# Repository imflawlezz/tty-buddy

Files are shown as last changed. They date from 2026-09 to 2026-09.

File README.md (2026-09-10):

# tty-buddy

A small status / console buddy for a Linux box: an **ESP32-C3** driving an
**ST7789 320×240** panel, plus a **Rust host daemon**.

**What it is for.**

Glance at host health without opening a terminal, or use the panel as a tiny
local console. Typical home-lab / desk use: CPU, memory, disk, network,
systemd units, and alerts on one side; a login shell on the other.

**What it does.**

- **Status mode** — live metrics on the LCD (hostname, clock, CPU / MEM /
  DISK, secondary fields, interfaces, services, optional alert strip).
- **Terminal mode** — 53×30 VT mirror of a PTY for a configured
  `shell_user`. A USB keyboard on the **host** (paths/names in
  `keyboard_devices`; empty = idle) is grabbed into that console in terminal
  mode.

The device has one push button for basic device controls. Short press opens
the OSD, or moves to the next row while it is open. Long press changes the
selected setting, or toggles mode when the OSD is closed.

The daemon talks to the board over USB-Serial/JTAG (`303a:1001`).

**Supported platforms**

- **Device** — ESP32-C3 SuperMini (USB-Serial/JTAG) with ST7789 **320×240**.
  Other C3 boards should work as long as the pinout matches.
- **Daemon** — Linux **amd64** and **arm64** (systemd).

Version: `1.1.0`.
License: [MIT](LICENSE).
Changes: [CHANGELOG.md](CHANGELOG.md).

| Path | Contents |
|---|---|
| [`firmware/`](firmware/) | Device firmware (PlatformIO) |
| [`daemon/`](daemon/) | Host daemon + packaging |
| [`hardware/`](hardware/) | Schematic, wiring, enclosure |
| [`docs/`](docs/) | Flashing, daemon lifecycle, config, architecture |

---

## Getting started

**What you need**

- Wired ESP32-C3 + ST7789 ([`hardware/wiring.md`](hardware/wiring.md))
- Merged factory firmware: `tty-buddy-firmware-<version>.bin`
- Daemon package (`.deb` or tarball) from a [GitHub Release](https://github.com/imflawlezz/tty-buddy/releases) or `make release`
- Linux host for the daemon (amd64 or arm64)

### Flash the board

#### In the browser

Chrome or Edge **89+** (Web Serial). Firefox and Safari are not supported.
Use HTTPS pages (the hosted tools already are).

| Tool | URL |
|---|-----|
| Espressif esptool-js | [espressif.github.io/esptool-js](https://espressif.github.io/esptool-js/) |
| Adafruit WebSerial ESPTool | [adafruit.github.io/Adafruit_WebSerial_ESPTool](https://adafruit.github.io/Adafruit_WebSerial_ESPTool/) |

Connect the board, choose the serial port, select the factory `.bin`, flash
at offset **0x0** (full image). Steps and troubleshooting:
[`docs/guides/flashing.md`](docs/guides/flashing.md).

If a daemon is already running, free the serial port before flashing:

```bash
sudo systemctl stop 'tty-buddy@*' 'tty-buddy-board@*'
```

#### On the machine (board on USB):

```bash
# from a release artifact or make firmware → dist/
cd firmware
./scripts/flash.sh /path/to/tty-buddy-firmware-<version>.bin
```

Optional port override:

```bash
./scripts/flash.sh --port /dev/ttyACM0 /path/to/tty-buddy-firmware-<version>.bin
```

No path argument runs a PlatformIO upload at the usual offsets. `flash.sh`
prefers `/dev/tty-buddy`, then Espressif `303a:1001`.

### Install / update the daemon

Pick one packaging form. Both install the binary, udev rule
(`/dev/tty-buddy`), systemd template `tty-buddy@<user>`, set `shell_user`,
and add the user to `dialout` + `input` groups. Replug USB if the symlink is
missing; a new login may be needed for group membership to take effect.

Instance user: `TTY_BUDDY_USER`, else `SUDO_USER` (non-root). Same for
`.deb` postinst and tarball `install.sh`. Detail:
[`docs/guides/daemon.md`](docs/guides/daemon.md).

`shell_user` must match the user running `tty-buddy@<user>`. The daemon does
not switch users at runtime; it starts that user’s login shell inside the PTY.

#### `.deb` (Debian / Ubuntu)

Same command installs or upgrades. Use the package that matches the host
arch:

```bash
sudo apt-get install -y ./tty-buddy_<version>_amd64.deb
```

```bash
sudo apt-get install -y ./tty-buddy_<version>_arm64.deb
```

Check the instance unit (username = the account that ran install /
`SUDO_USER`):

```bash
systemctl status tty-buddy@$USER
```

#### Tarball (portable)

Unpack and run `install.sh` as root. On upgrade it replaces the binary,
unit, udev rule, and helpers; existing `daemon.toml` / `buddy.config` are
left alone. First install copies defaults when those files are missing.

```bash
# change `x86_64` to `aarch64` for arm64 tarball
tar xzf tty-buddy-<version>-x86_64-linux.tar.gz
cd tty-buddy-<version>-x86_64-linux
sudo ./install.sh
```

Override the instance user when needed:

```bash
# replace alice with real local username
sudo TTY_BUDDY_USER=alice ./install.sh
```

If the unit was already running, restart it after upgrade:

```bash
sudo systemctl restart tty-buddy@$USER
```

Optional check:

```bash
systemctl status tty-buddy@$USER
```

#### Several boards on one host

Single-board installs need no extra config (`/dev/tty-buddy` +
`tty-buddy@$USER`). For additional boards, udev also creates
`/dev/tty-buddy-<serial>`; register each with:

```bash
tty-buddy devices
sudo /usr/lib/tty-buddy/configure-instance.sh add-board "$USER" '<serial>'
```

That creates `/etc/tty-buddy/instances/<id>/` and enables
`tty-buddy-board@<id>`. If `serial` is set and no board matches, discovery
fails closed. Details: [daemon guide](docs/guides/daemon.md#several-boards-on-one-host).

### Keyboard on the host

USB keyboards are handled by the **daemon**, not the ESP. Prefer a stable
udev path under `/dev/input/by-id/` (the `*-event-kbd` node, not mouse /
hidraw / joystick).

```bash
ls /dev/input/by-id/
```

Allowlist that device in `buddy.config` (paths and/or case-insensitive name
substrings). **Empty `keyboard_devices` opens no keyboards** (status watch
and terminal grab both stay idle) and logs a warning. If open fails with
EACCES, ensure the instance user is in `input` and re-login. Shipped default
is `keyboard_opens_terminal = false`. For a **kiosk** / dedicated console,
set `true` so typing in status opens terminal:

```ini
[behavior]
keyboard_opens_terminal = false   # kiosk: set true
keyboard_layout = us              # us | pl | de (raw keycodes, not XKB; AltGr on pl/de)
keyboard_devices = /dev/input/by-id/usb-…-event-kbd
# or: keyboard_devices = NuPhy
```

`pl` is QWERTZ Y/Z with a US digit row; AltGr types Polish diacritics. `de`
can emit German letters and AltGr symbols. Panel glyphs for Polish/German
codepoints are firmware-side display; other scripts may show `?`.

With `keyboard_opens_terminal = true`, watched keys can open terminal from
status. While terminal mode is active, tty-buddy **EVIOCGRAB**s allowlisted
keyboards (even if auto-open is `false`), which can steal the desktop
keyboard. Detail: [`docs/guides/daemon.md`](docs/guides/daemon.md),
[`docs/reference/configuration.md`](docs/reference/configuration.md).

### Configuration

| File | Role |
|---|---|
| `/etc/tty-buddy/daemon.toml` | Device bind + `shell_user` |
| `/etc/tty-buddy/buddy.config` | Panel UX (behavior, layout, display, …) |

```ini
# Example desktop fragment (not the full shipped template)
[behavior]
startup_mode = status
keyboard_opens_terminal = false
fps = 10
keyboard_layout = us
keyboard_devices = /dev/input/by-id/usb-EXAMPLE-event-kbd

[globals]
label_color = #888888
background_color = #000000

[header]
hostname_color = #FFFFFF
date_color = #888888
time_color = #FFFFFF
date_format = %d-%m-%Y
time_format = %H:%M:%S

# ...
```

Full config reference (including display / `wake_on_alert` sleep policy):
[`docs/reference/configuration.md`](docs/reference/configuration.md).

### Uninstall

Pick one command, depending on whether you want to keep the configs for
future reinstalls. More detail: [`docs/guides/daemon.md`](docs/guides/daemon.md).

#### `.deb`

```bash
sudo apt-get remove tty-buddy
# or purge to remove configs as well
sudo apt-get purge tty-buddy
```

#### Tarball

```bash
# remove binary / unit / udev, keep configs
sudo /usr/lib/tty-buddy/uninstall.sh

# remove binary / unit / udev, delete /etc/tty-buddy
sudo /usr/lib/tty-buddy/uninstall.sh --purge
```

---

## Build and development

**Tools:** PlatformIO (`pio`) for firmware; Rust stable + `pkg-config` /
`libudev-dev` for the daemon on Linux. On macOS, `.deb` builds use Docker
when `dpkg-deb` is missing.

Release / package targets (version from `daemon/Cargo.toml` → `dist/`):

```bash
make help          # list targets
make version       # print version string
make firmware      # merged factory .bin
make daemon        # .deb + tarball (this host arch)
make daemon-all    # .deb + tarball for amd64 and arm64
make release       # firmware + daemon + checksums.txt
make release-all   # firmware + daemon-all + checksums.txt
make checksums     # SHA-256 for artifacts already in dist/
make clean         # remove dist/ and local build outputs
```

Checks used in CI:

```bash
cd daemon && cargo fmt --all -- --check && cargo clippy --all-targets -- -D warnings && cargo test
```

```bash
cd firmware && pio test -e native && pio run -e esp32-c3-supermini
```

Maintainer detail: [`docs/guides/development.md`](docs/guides/development.md).

- CI: [`.github/workflows/ci.yml`](.github/workflows/ci.yml)
- Draft GitHub Releases on `v*` tags (tag must match Cargo version):
  [`.github/workflows/release.yml`](.github/workflows/release.yml)

---

Made with ❤️ by [imflawlezz](https://github.com/imflawlezz)

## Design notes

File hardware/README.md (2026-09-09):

# Hardware

ESP32-C3 SuperMini + ST7789 320×240 panel, one front button, PWM backlight.

## Contents

| Path | Contents |
|---|---|
| [`schematics/tty-buddy/`](schematics/tty-buddy/) | KiCad project (schematic + symbol lib) |
| [`schematics/tty-buddy/export/tty-buddy-schematic.pdf`](schematics/tty-buddy/export/tty-buddy-schematic.pdf) | Schematic PDF |
| [`wiring.md`](wiring.md) | Pin table matching firmware `User_Setup.h` / OSD pins |
| [`cad/`](cad/) | Enclosure (`tty-buddy-enclosure.f3d`) and exports under `cad/export/` (STEP / STL / 3MF) |

## Electrical summary

- **Display:** SPI ST7789 — SCK GPIO4, MOSI GPIO6, CS GPIO7, DC GPIO3, RST
  GPIO2.
- **Backlight:** GPIO5 PWM (firmware). May be tied to 3V3 for always-on (no
  dimming).
- **Button:** GPIO10 to GND, internal pull-up (`INPUT_PULLUP` in firmware).
- **Power:** USB on the SuperMini. Schematic does not use the board 5V pin
  for the panel.

Full pin table: [`wiring.md`](wiring.md). Source of truth for nets: the KiCad schematic.

## Firmware alignment

Pins are fixed in:

- [`firmware/include/User_Setup.h`](../firmware/include/User_Setup.h) — TFT SPI
- [`firmware/src/osd.cpp`](../firmware/src/osd.cpp) — `PIN_BL = 5`, `PIN_BTN = 10`

Rotation and colour order assume a 320×240 module with `TFT_BGR` and
`TFT_INVERSION_OFF` as configured in `User_Setup.h`.

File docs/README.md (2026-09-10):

# Documentation

Detailed notes beyond the root [README](../README.md).

## In this tree

| Document | Topic |
|---|---|
| [guides/flashing.md](guides/flashing.md) | Firmware images and how to flash them |
| [guides/daemon.md](guides/daemon.md) | Daemon install, upgrade, uninstall, keyboard allowlist, multi-board |
| [reference/configuration.md](reference/configuration.md) | `daemon.toml`, `buddy.config` (incl. `keyboard_devices` / layouts), CLI |
| [reference/protocol.md](reference/protocol.md) | Serial frame and StatusSnap layout |
| [architecture/overview.md](architecture/overview.md) | Host ↔ device responsibilities |
| [guides/development.md](guides/development.md) | Build, test, local packages |

## Elsewhere in the repo

| Document | Topic |
|---|---|
| [README.md](../README.md) | Project overview and getting started |
| [CHANGELOG.md](../CHANGELOG.md) | Release history |
| [LICENSE](../LICENSE) | MIT license |
| [hardware/](../hardware/) | Schematic, wiring, enclosure |
| [hardware/wiring.md](../hardware/wiring.md) | Pin table aligned with firmware |
| [daemon/buddy.config](../daemon/buddy.config) | Shipped panel config template |
| [daemon/packaging/daemon.toml.example](../daemon/packaging/daemon.toml.example) | Shipped host config template |

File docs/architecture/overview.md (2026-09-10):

# Architecture

tty-buddy is a **host daemon** plus **ESP32-C3 firmware**. The host owns
metrics, the login PTY, and the USB keyboard. The device owns the LCD, the
front-button OSD, backlight PWM, and sleep. They exchange CRC-framed
messages over USB-Serial/JTAG (CDC). Wire details: [protocol reference](../reference/protocol.md).

## Why this split

The SuperMini presents only a **USB device** port (Serial/JTAG). It cannot
host a keyboard. Putting the keyboard and PTY on Linux keeps the ESP as a
display + input bridge for one button, and lets status metrics use normal
Linux APIs (`/proc`, `systemctl`, and `ip addr`).

## Runtime roles

### Host (`daemon/`)

Entry point: `tty-buddy run` (systemd `tty-buddy@<user>`).

| Concern | Module / area |
|---|---|
| Device discovery | `discover` — `device_path` → fail-closed `serial` → vid/pid → Espressif → `/dev/tty-buddy` / first (see [configuration](../reference/configuration.md#discovery-pick_device)) |
| Session loop | `bridge` — reconnect forever; status vs terminal; config reload |
| Metrics → StatusSnap | `metrics` + `status_config` |
| PTY + vt100 grid | `terminal` (53×30, same cell geometry as the panel) |
| Keyboard | `keyboard` — allowlisted only; **watch** in status if `keyboard_opens_terminal`; **EVIOCGRAB** in terminal |
| Framing / ACK | `serial_io` + `protocol` |
| Settings paths | `settings`, `status_config` |

**Status mode.** Sample about once per second, pack StatusSnap v13, send
with `FLAG_STATUS`. Optionally watch allowlisted keyboards when
`keyboard_opens_terminal` is set; activity can switch to terminal and set
`FLAG_ACTIVITY` (wake). Style (`FLAG_STYLE`) is pushed when config/metrics
style inputs change; the device dirties status chrome when that style differs
while already in status mode.

**Terminal mode.** Spawn the systemd instance user’s login shell inside a
PTY and push the cell payload at up to `fps` (keystrokes force an immediate
frame). Allowlisted host keyboards are **always EVIOCGRAB’d** while terminal
mode is active (device toggle or keyboard activity), even when
`keyboard_opens_terminal = false`. Empty `keyboard_devices` means no USB
keyboard I/O. `keyboard_layout` maps raw keycodes in the daemon (not XKB),
with per-device modifiers (incl. CapsLock / AltGr).
Cursor flags and activity wake the panel when needed.

**Config.** `daemon.toml` is host/install (device bind, `shell_user`, path
to panel config). `buddy.config` is panel UX and behaviour; mtime reload
applies without restarting the unit. Brightness/sleep events from the device
rewrite `[display]` when linked.

### Device (`firmware/`)

PlatformIO env `esp32-c3-supermini` (Arduino + TFT_eSPI). Native env builds
protocol and Unicode glyph unit tests.

| Concern | Area |
|---|---|
| Link + modes | `main` — wait for host, status vs terminal paint |
| Status layout | `status_ui` — header / hero / secondary / ifaces / services / alerts |
| VT cells | `terminal` — 53×30; ASCII Font1, curated PL/DE bitmaps, procedural box/Braille |
| Button, BL, sleep | `osd` — GPIO10 button, GPIO5 PWM, NVS when offline |
| Wire decode | `protocol` — shared with host tests |

**Button.** Short press: open OSD or advance the highlighted row; may
dismiss an alert if configured. Long press: change the selected OSD value,
or toggle mode when the OSD is closed. Idle auto-close for OSD is timed
separately from sleep. With `wake_on_alert`, an active alert wakes the panel
and postpones sleep until the alert clears (timer restarts then); OSD idle
auto-close still runs.

**Factory image.** Post-build `merge_factory.py` merges bootloader,
partitions, boot_app0, and app into `tty-buddy-firmware-<ver>.bin` (version
from `daemon/Cargo.toml`). That file is what releases flash at **0x0**.

## Data flow (summary)

Three paths share the same USB CDC link.

**Status** — host samples metrics, applies `buddy.config`, pushes style/status
frames; device paints `status_ui`.

```mermaid
flowchart LR
  M[Linux metrics] --> S[StatusStyle + layout]
  C[buddy.config] --> S
  S --> W[FLAG_STYLE / FLAG_STATUS]
  W --> U[status_ui]
```

**Terminal** — PTY grid and keyboard activity become framed cell payloads.

```mermaid
flowchart LR
  K[evdev keys] --> P[PTY + vt100]
  P --> F[53×30 framed cells]
  F --> T[terminal]
```

Keys in status mode can open terminal (no grab). In terminal mode they are
grabbed into the PTY.

**Device → host** — button / OSD events; brightness and sleep may rewrite
`buddy.config`.

```mermaid
flowchart LR
  O[osd / button] --> E[DEV_MODE_TOGGLE / DEV_OSD_*]
  E --> B[bridge]
  B --> C[buddy.config writeback]
```

## Packaging on the host

- Binary: `/usr/bin/tty-buddy`
- Units: `tty-buddy@.service` (instance = Linux user); optional
  `tty-buddy-board@.service` (instance = board id)
- udev: Espressif `303a:1001` → `/dev/tty-buddy` and `/dev/tty-buddy-<serial>`
- Config dir: `/etc/tty-buddy/` (per-board under `instances/<id>/`)

Install scripts bind `shell_user`, groups, and `buddy.config` ownership to
that user. See [daemon package lifecycle](../guides/daemon.md).

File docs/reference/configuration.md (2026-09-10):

# Configuration reference

Two files after a normal install:

| File | Role | Edited by | Applied |
|---|---|---|---|
| `daemon.toml` | Host bind: serial device, `shell_user`, path to panel file | packaging, `tty-buddy setup`, admin | **Process restart** |
| `buddy.config` | Panel UX: layout colours, behaviour, alerts, display/OSD | user, OSD writeback | **mtime poll** in the running session |

Shipped templates:

- [`daemon/packaging/daemon.toml.example`](../../daemon/packaging/daemon.toml.example)
- [`daemon/buddy.config`](../../daemon/buddy.config)

Installed defaults: `/etc/tty-buddy/daemon.toml`,
`/etc/tty-buddy/buddy.config`.

Implementation: [`daemon/src/settings.rs`](../../daemon/src/settings.rs), [`daemon/src/status_config.rs`](../../daemon/src/status_config.rs),
[`daemon/src/bridge.rs`](../../daemon/src/bridge.rs). Wire fields: [protocol](protocol.md).

---

## Reload matrix

| Change | Effect |
|---|---|
| Any `daemon.toml` key | Restart `tty-buddy@…` (or the process) |
| `buddy.config` mtime | Re-parse; push `FLAG_STYLE`; update `fps`. Keyboard allowlist/layout reapplied: watch (or ungrab) in **status**, re-grab in **terminal** |
| `startup_mode` while running | Stored in memory only — **does not** flip status ↔ terminal mid-session |
| CLI `--status` / `--terminal` | Applied once when the session starts; not re-applied on buddy reload |
| CLI `--fps` | Applied at session start and again on every buddy reload |
| Device USB reconnect | New session: reloads buddy.config; same in-memory `daemon.toml` + CLI overrides |
| OSD brightness / sleep on device | Rewrites `brightness` + `sleep_timeout` in buddy.config (see [OSD writeback](#osd-writeback)) |

Status snapshots stay ~1 Hz for `/proc` metrics (CPU, mem, disk, load, …).
Interface IPs (`ip`) and systemd service lists (`systemctl`) are cached for
about **3 seconds** between forks. `fps` caps **terminal** frame sends only.

---

## `daemon.toml`

TOML. Search order when `--config` is omitted ([`settings_path`](../../daemon/src/settings.rs)):

1. `./daemon.toml` if it exists
2. `/etc/tty-buddy/daemon.toml` if it exists
3. `$XDG_CONFIG_HOME/tty-buddy/daemon.toml` (via `dirs::config_dir`)
4. else `/etc/tty-buddy/daemon.toml`

Missing file → `DaemonSettings::default()`. Invalid or unreadable
`daemon.toml` aborts startup / setup (`DaemonSettings::load`); there is no
fail-open helper that swallows parse errors.

### Host keys

| Key | Type | Default (`Default` impl) | Meaning |
|-----|---|---|---|
| `device_path` | string? | unset | Preferred node (usually `/dev/tty-buddy` or `/dev/tty-buddy-<serial>`) |
| `vid` | u16? | `0x303A` (`12346`) | USB vendor |
| `pid` | u16? | `0x1001` (`4097`) | USB product (Espressif USB-Serial/JTAG) |
| `serial` | string? | unset | Disambiguate when several boards share vid/pid |
| `buddy_config` | path? | `/etc/tty-buddy/buddy.config` | Panel INI. **Alias:** `status_config` |
| `shell_user` | string? | unset | Login shell identity inside the PTY; must match the daemon runtime user / systemd instance |

If a **present** file omits `buddy_config`, serde yields `None` and the
[panel path resolver](#panel-file-resolution) searches the usual candidates (unlike `Default`, which
sets `/etc/tty-buddy/buddy.config`).

### Discovery (`pick_device`)

1. `device_path` if that path exists
2. Else if `serial` is set: match that serial (optionally narrowed by `vid`/`pid`).
   **No match → fail closed** (do not fall through to another board)
3. Else match `vid`/`pid` (first / only hit)
4. Else first Espressif `303a:1001`
5. Else sole listed tty / `/dev/tty-buddy` / first candidate

`tty-buddy devices` lists candidates (including `/dev/tty-buddy` and
`/dev/tty-buddy-*` udev symlinks). `tty-buddy setup` writes host fields
only (see [CLI](#cli)).

For multi-board hosts, prefer `configure-instance.sh add-board` (creates
`/etc/tty-buddy/instances/<id>/` + `tty-buddy-board@<id>`), or set `serial`
and `device_path=/dev/tty-buddy-<serial>` yourself. Bare `/dev/tty-buddy` is
ambiguous when more than one board is plugged in.

### Legacy behaviour keys (host file)

Still deserialized:

| Key | Default | Notes |
|-----|---|---|
| `start_in_status` | `true` | |
| `keyboard_opens_terminal` | `false` | |
| `fps` | `10.0` | |

They apply **only** when buddy.config has **no** `[behavior]` section
(`apply_daemon_behavior_fallback`). `DaemonSettings::save` / `setup`
**omit** them — behaviour belongs in buddy.config.

---

## `buddy.config`

INI. Section and key names are trimmed and **ASCII-lowercased**. Blank lines
and full-line `#` / `;` comments are skipped. Inline comments (`#` / `;`)
count only when preceded by whitespace. Keys before the first `[section]`
are ignored. Missing file → built-in defaults (no error).

### Panel file resolution

[`resolve_buddy_config_path`](../../daemon/src/settings.rs) — first **existing file** among:

1. Path from `daemon.toml` / `--buddy-config`
2. `./buddy.config`
3. `/etc/tty-buddy/buddy.config`
4. `./status.config`
5. `/etc/tty-buddy/status.config`

If none exist → configured path, else `/etc/tty-buddy/buddy.config`.

### Shared value types

**Bool** (`as_bool`): `1` / `true` / `yes` / `on` → true; `0` / `false` /
`no` / `off` → false; empty or anything else → the call’s default.

**Colour** (`parse_hex_color`): optional `#`; 3-digit hex expands (`#F00` →
`FF0000`); else 6 hex digits; bare `888888` accepted. Invalid → caller
default. Stored as RGB565 on the wire.

**Date / time formats**: C-style `%` tokens mapped on the host (
[`strftime_chrono`](../../daemon/src/metrics.rs)). Supported: `Y y m d H I M S b B a A p %`. Unknown `%X`
is left as the literal `%X`. Not full libc strftime.

---

### `[behavior]`

Presence sets `behavior_from_file` and disables daemon.toml legacy behaviour
keys.

| Key | Alias | Default | Semantics |
|-----|---|---|---|
| `startup_mode` | `start_in_status` | status | Terminal if value is `terminal`, `console`, `tty`, `false`, `0`, `no`, or `off` (case-insensitive). **Any other string → status** |
| `keyboard_opens_terminal` | — | `false` | In status mode, watch allowlisted keyboards without grab; any activity opens terminal and sets activity/wake. Shipped default is off (safe for shared desktops). **Kiosk / dedicated console:** set `true` |
| `fps` | — | `10` | Terminal frame cap; parsed value `.max(1.0)` |
| `keyboard_layout` | — | `us` | Evdev→PTY map (not XKB). `us`; `pl` = QWERTZ Y/Z + US digit/punct + AltGr Polish diacritics; `de` = QWERTZ + German letters + AltGr symbols. Also: CapsLock, F1–F12, Delete/Home/End/PgUp/PgDn. Aliases: `en`/`qwerty`→us, `pl_qwertz`/`polish`→pl, `de_qwertz`/`german`→de |
| `keyboard_devices` | `keyboard_device` | empty | Allowlist: `/dev/input/by-id/…` paths and/or case-insensitive name substrings (comma-separated). **Empty → no keyboards opened** + warning |

`keyboard_opens_terminal = true` is for a **kiosk** / dedicated host console:
typing on a watched keyboard can pull the panel into terminal mode. The shipped
default is `false` so a shared desktop does not auto-open terminal on key
activity. While terminal mode is active, allowlisted keyboards are still
grabbed even when this flag is `false`.

**Allowlist.** List candidates with `ls /dev/input/by-id/` and pick the
`*-event-kbd` symlink for the board you want (skip `*-event-mouse`,
`*-hidraw`, `*-event-joystick`), or use a name substring. Without
`keyboard_devices`, terminal mode will not receive USB keyboard input even
when `keyboard_opens_terminal` is true. Firmware PL/DE glyphs render those
codepoints in the grid; `keyboard_layout = pl` uses AltGr for Polish
diacritics (ąęć…). Example:

```ini
[behavior]
startup_mode = status
keyboard_opens_terminal = false
fps = 10
keyboard_layout = pl
keyboard_devices = /dev/input/by-id/usb-NuPhy_Air75_V3_NuPhy_Keybord_0720-event-kbd
```

Packaging may prepend a default `[behavior]` block if missing
([daemon lifecycle](../guides/daemon.md)). That default does **not** set
`keyboard_devices` — configure it after install.

---

### `[globals]`

| Key | Alias | Default |
|-----|---|---|
| `label_color` | — | `#888888` |
| `background_color` | `background` | `#000000` |

---

### `[header]`

| Key | Default |
|-----|---|
| `hostname_color` | white |
| `date_color` | `#888888` |
| `time_color` | white |
| `date_format` | `%d-%m-%Y` (applied only if non-empty) |
| `time_format` | `%H:%M:%S` (applied only if non-empty) |

---

### `[hero]`

CPU / MEM / DISK meters and thresholds.

| Key | Aliases | Default / notes |
|-----|---|---|
| `cpu_color` | `cpu` | white if empty |
| `mem_color` | `mem` | white if empty |
| `disk_color` | `disk` | white if empty |
| `disk_mount` | — | `/` (non-empty only) |
| `meter_mode` | — | bool; **if the section is present and the key is omitted, treated as `true`** |
| `warn_at` | — | `60` (`u8`; parse fail → 60; no clamp). If `warn_at > crit_at` after parse, the two values are **swapped** |
| `crit_at` | — | `90` (same swap rule as `warn_at`) |
| `level_ok_color` | `level_ok` | `#33AA33` |
| `level_warn_color` | `level_warn` | `#CCCC33` |
| `level_crit_color` | `level_crit` | `#CC3333` |

---

### `[secondary]`

Two optional fields under the hero row.

| Key | Values |
|-----|---|
| `left` / `right` | `uptime` / `up` → uptime; `load` → load average; `swap` → swap; `""` / `none` / `blank` / unknown → hidden |
| `left_color` / `right_color` | empty → white |

Code defaults both sides to hidden (`SEC_NONE`). The shipped template sets
`left = uptime`, `right = load`.

---

### `[interfaces]`

Each key is an interface name (stored lowercased); value is the address
mode. **File order is preserved.** At most **16** interfaces are sampled
onto the wire.

| Value | Mode |
|---|---|
| `v6`, `6`, `ipv6` | IPv6 |
| `auto`, `any`, `both` | Prefer IPv4; else non-`fe80:` IPv6; else link-local |
| anything else (incl. `v4`, `4`, `ipv4`, garbage) | IPv4 |

Empty section / no keys → no interface rows. The shipped template leaves this
section empty on purpose; add only the interfaces you want shown. Address
lookups use `ip` and share the ~3 s slow-poll cache with services (see
[Reload matrix](#reload-matrix)).

---

### `[services]`

| Key | Aliases | Notes |
|-----|---|---|
| `filter` | — | Missing → `"all"`. `""` / `all` / `*` → unfiltered. Else comma-separated unit names; `.service` appended if absent; names ending in `@` skipped |
| `active_color` | `active` | |
| `failed_color` | `failed` | |
| `inactive_color` | `inactive` | |
| `activating_color` | `activating` | |
| `reloading_color` | `reloading` | |
| `deactivating_color` | `deactivating` | |
| `maintenance_color` | `maintenance` | |

Unfiltered: `systemctl list-units --type=service --all …`, then sort failed
→ transitioning → active → inactive → other, truncate to **80**. Filtered:
one batched `systemctl is-active` for the listed units (same sort/truncate).
Display names strip `.service` and truncate to **40** characters. Fresh
`systemctl` forks are rate-limited by the ~3 s slow-poll cache (see
[Reload matrix](#reload-matrix)).

---

### `[alerts]`

If the section is **absent**, `alert_mask` stays `0` (alerts off) — even
though code defaults for colours/temp still exist. The shipped template
includes `[alerts]` with sources enabled.

If the section is **present**, bits are OR’d from the per-source bools, then
`enabled = false` clears the whole mask.

| Key | Default if missing | Bit |
|-----|---|-----|
| `cpu_crit` | `true` | CPU over `crit_at` |
| `mem_crit` | `true` | MEM over `crit_at` |
| `disk_crit` | `true` | DISK over `crit_at` |
| `temp_crit` | `true` | temperature ≥ `temp_crit_c` |
| `service_failed` | `true` | failed units |
| `service_inactive` | **`false`** | inactive units (noisy; off by default) |
| `enabled` | — | if present and false → mask `0` |
| `background_color` | `#990000` | |
| `text_color` | white | |
| `hold_sec` | `0` | `0` / `""` / `until_clear` / `until-clear` / `clear` → hold until condition clears; else seconds (`u8`) |
| `temp_crit_c` | `80` | parse fail → 80 |

---

### `[display]` (legacy `[osd]`)

Read as `[display]`, else `[osd]`. If both exist, **`[display]` wins**. OSD
writeback always rewrites the header as `[display]`.

When this section is present, OSD flags are **rebuilt from zero** (not
merged with the previous default bitset).

| Key | Aliases | Semantics |
|-----|---|---|
| `brightness` | `default_brightness` | `auto` → auto mode (level `0` + auto flag). Else `u8` clamped with `.min(100)` on parse |
| `auto_brightness` | — | bool (default false); also set when `brightness = auto`. Writeback **drops** this key in favour of `brightness = auto` |
| `sleep_timeout` | `sleep_timeout_sec` | `never` / `""` → never (`0`). Else integer (see levels below) |
| `auto_day_level` | `auto_day_pct` | `.min(100)`; firmware maps 1–6 as steps, `>6` as approximate % |
| `auto_night_level` | `auto_night_pct` | same |
| `auto_day_hour` / `auto_night_hour` | — | local hour 0–23 (`.min(23)`) |
| `dismiss_alert_on_tap` | — | default `true` — short press dismisses alert instead of only opening OSD |
| `wake_on_alert` | — | default `true` — see below |

When `wake_on_alert` is true:

- an active status alert wakes the panel if it was asleep
- while the alert is up, the sleep timeout does **not** arm
- when the alert clears, the sleep timer restarts from that moment
- OSD idle auto-close is separate and still runs during an alert

When false, alerts do not wake sleep or postpone it.

#### Brightness and sleep levels

Intended form (what OSD writeback persists): **steps `1`–`6`**, plus `auto`
/ `never`.

Firmware ([`osd.cpp`](../../firmware/src/osd.cpp)):

| Brightness step | PWM duty | ~% |
|---|---|-----|
| 1 | 42 | 16 |
| 2 | 85 | 33 |
| 3 | 128 | 50 |
| 4 | 170 | 67 |
| 5 | 213 | 84 |
| 6 | 255 | 100 |

| Sleep value | Meaning |
|---|---|
| `0` / `never` | Never sleep |
| `1` | 30 s |
| `2` | 60 s |
| `3` | 2 min |
| `4` | 5 min |
| `5` | 10 min |
| `6` | 30 min |

Host → device:

- Brightness `1`–`6` → step; `>6` → treat as percent and map onto six steps;
  `0` + auto flag → auto.
- Sleep `0`–`6` → level index; **`>6` treated as seconds** and mapped onto
  the nearest `SLEEP_SECS` entry.

So `sleep_timeout = 4` in the shipped file is **level 4 (5 minutes)**, not 4
seconds. Prefer levels (or `never`) in hand-edited files; raw seconds also
work if `>6`.

---

## OSD writeback

Device → host events (`DEV_OSD_BRIGHT` / `DEV_OSD_SLEEP`): levels `0`–`6`
(`0` = auto / never).

The bridge updates in-memory style and calls `write_osd_levels` on the
active buddy.config path (temp file + rename when the directory is writable;
falls back to in-place overwrite when only the file is writable, e.g. root-owned
`/etc/tty-buddy` with a user-owned config):

- Rewrites only `brightness` and `sleep_timeout`
- Renames `[osd]` → `[display]`
- Replaces legacy `default_brightness` / `sleep_timeout_sec`
- Drops `auto_brightness` lines
- Updates recorded mtime so the next poll does not thrash-reload
- Does **not** push a style frame afterward (device already applied locally)

Other `[display]` keys are left alone.

---

## CLI

```text
tty-buddy run   [--config PATH] [-p|--port PATH]
                [--buddy-config PATH] [--fps N] [--status | --terminal]
tty-buddy setup [--config PATH]
tty-buddy devices
tty-buddy probe [--buddy-config PATH]
```

| Flag / command | Effect |
|---|---|
| `--config` | `daemon.toml` path (skips search) |
| `-p` / `--port` | Force `device_path` for this process |
| `--buddy-config` | Panel file (`--status-config` alias) |
| `--fps` | Override fps (`.max(1.0)`); reapplied on buddy reload |
| `--status` | Force status mode at session start |
| `--terminal` | Force terminal mode; if both flags set, **`--terminal` wins** (applied last) |
| `setup` | Interactive device pick; `save` host-only fields |
| `devices` | List serial candidates |
| `probe` | Load panel config, sample metrics twice, print summary — **no serial open** |

Systemd default: `ExecStart=/usr/bin/tty-buddy run --config /etc/tty-buddy/daemon.toml`
(`tty-buddy@<user>`). Board instances use
`/etc/tty-buddy/instances/%i/daemon.toml` (`tty-buddy-board@<id>`).

`shell_user` is not a uid switch. The daemon already runs as `tty-buddy@<user>`
(or the `User=` from a board-instance drop-in) and spawns that same user’s
login shell (`$SHELL -l`, home/env from `/etc/passwd`) inside the PTY. A
mismatched `shell_user` causes startup to fail.

---

## Migration notes

| Old | Current |
|-----|---|
| `/etc/tty-buddy/status.config` | Still resolved if `buddy.config` is absent; packaging may rename |
| TOML `status_config` | Alias of `buddy_config` |
| `[osd]` | Still read; writeback normalizes to `[display]` |
| Behaviour in `daemon.toml` | Legacy fallback only without `[behavior]` |
| `default_brightness` / `sleep_timeout_sec` / `auto_brightness` | Still read; writeback canonicalizes |

---

## Minimal examples

Host (after install / `setup`):

```toml
device_path = "/dev/tty-buddy"
vid = 12346
pid = 4097
buddy_config = "/etc/tty-buddy/buddy.config"
shell_user = "alice"
```

Panel behaviour + display (fragment):

```ini
[behavior]
startup_mode = status
keyboard_opens_terminal = false
fps = 10
keyboard_layout = us
keyboard_devices = /dev/input/by-id/usb-EXAMPLE-event-kbd

[display]
brightness = 4
sleep_timeout = 4
wake_on_alert = true
dismiss_alert_on_tap = true
```

Full colour / interface / service layout: copy [`daemon/buddy.config`](../../daemon/buddy.config) and
edit.

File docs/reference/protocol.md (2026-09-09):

# Serial protocol

Authoritative constants: [`daemon/src/protocol.rs`](../../daemon/src/protocol.rs) and
[`firmware/src/protocol.h`](../../firmware/src/protocol.h) / [`protocol.cpp`](../../firmware/src/protocol.cpp). Keep both sides in sync.

## Link

USB-Serial/JTAG CDC to the ESP32-C3. Host writes framed messages and expects
ACK/NAK. Device may emit single-byte opcodes (optionally plus one data byte)
toward the host for OSD / mode.

## Host → device frame

| Field | Size | Notes |
|---|---|---|
| Magic | 4 | `AA 55 A5 5A` |
| Header | 4 | `seq`, `cx`, `cy`, `flags` |
| Payload | 4770 | `53 × 30 × 3` bytes |
| CRC | 2 | CRC-CCITT (init `0xFFFF`, poly `0x1021`) over header+payload |

Total frame length: **4780** bytes.

Cell encoding (terminal): three bytes per cell (glyph / colour pair as used
by the firmware terminal renderer). Status and style modes reuse the same
payload size; meaningful data occupies the leading StatusSnap region,
remainder zero.

### Flags (`flags` byte)

| Bit / value | Name | Meaning |
|---|---|---|
| `0x01` | `FLAG_CURSOR_VISIBLE` | Cursor position is meaningful |
| `0x02` | `FLAG_CURSOR_ON` | Cursor blink phase on |
| `0x04` | `FLAG_ACTIVITY` | User activity — wake / refresh |
| `0x10` | `FLAG_STYLE` | Payload carries style (from StatusSnap packing). While already in status mode, the device refreshes chrome if style bytes changed — no need to wait for a differing `FLAG_STATUS` snap |
| `0x20` | `FLAG_STATUS` | Payload carries StatusSnap metrics |
| `0x80` | `FLAG_BYE` | Session teardown blank |

`cx` / `cy` are cursor coordinates when cursor flags are set (terminal).

### Device replies

| Byte | Name | Meaning |
|---|---|---|
| `0x06` | ACK | Frame accepted |
| `0x15` | NAK | Reject / retry |

## Device → host opcodes

| Byte | Name | Payload |
|---|---|---|
| `0x12` | `DEV_MODE_TOGGLE` | none — toggle status ↔ terminal |
| `0x13` | `DEV_OSD_BRIGHT` | 1 byte: `0` = auto, `1`–`6` = step |
| `0x14` | `DEV_OSD_SLEEP` | 1 byte: `0` = never, `1`–`6` = level |

The host maps bright/sleep into `buddy.config` `[display]` when connected.

## StatusSnap (v13)

- Version constant: `STATUS_VER = 13`
- Packed length: **4466** bytes (`STATUS_SNAP_LEN`)
- Carried in the frame payload when `FLAG_STATUS` (and style via
  `FLAG_STYLE` using the same packing helpers)

Includes (among other fields): hostname/date/time strings, CPU/MEM/DISK and
optional temperature, load/uptime/swap, up to **16** interfaces, up to
**80** service rows (40-byte names), alert mask/colours/hold, and
OSD-related style fields (brightness step, sleep level, auto day/night,
flags).

Service status codes and alert bit masks are defined in `protocol.rs`
(`ST_SVC_*`, `AL_*`, `OSD_F_*`). Secondary column ids: `SEC_UPTIME` /
`SEC_SWAP` / `SEC_LOAD` / `SEC_NONE`.

Native firmware tests (`pio test -e native`) and daemon unit tests assert
sizes, packing invariants, wire constants (`FLAG_*` / `DEV_*` / ACK/NAK),
and shared golden vectors for `StatusStyle` bytes plus empty-frame CRC —
prefer those over re-deriving layouts by hand. Keep both sides’ goldens in
lockstep when the wire format changes.

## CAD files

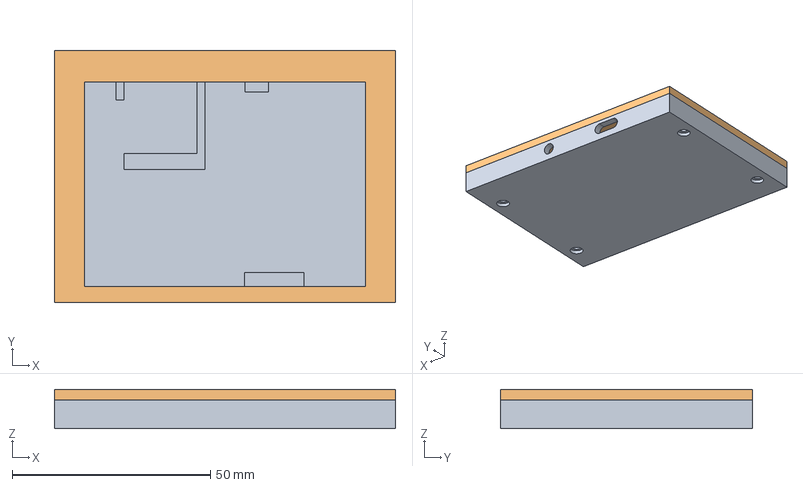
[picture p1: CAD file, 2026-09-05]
hardware/cad/export/tty-buddy-assembly.step
86.0 x 63.5 x 9.90 mm

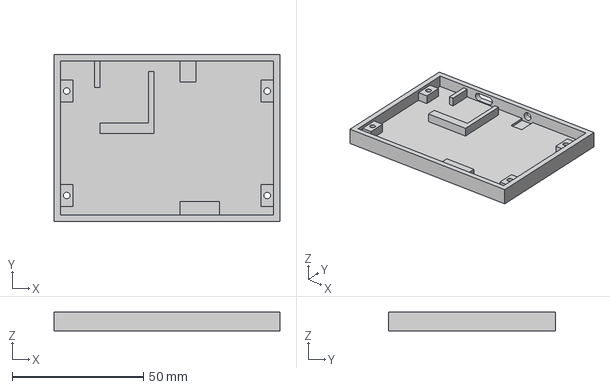
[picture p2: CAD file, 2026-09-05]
hardware/cad/export/tty-buddy-body.step
86.0 x 63.5 x 7.20 mm

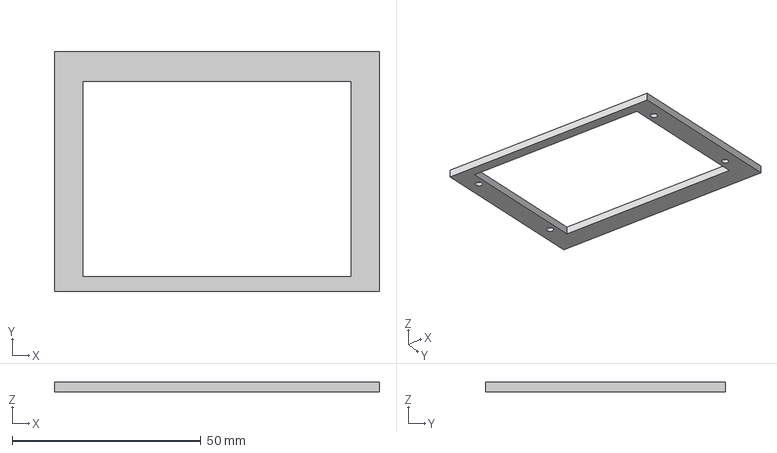
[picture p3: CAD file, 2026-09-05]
hardware/cad/export/tty-buddy-lid.step
86.0 x 63.5 x 2.70 mm

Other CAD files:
hardware/cad/export/tty-buddy-body.3mf
hardware/cad/export/tty-buddy-body.stl
hardware/cad/export/tty-buddy-lid.3mf
hardware/cad/export/tty-buddy-lid.stl
hardware/cad/tty-buddy-enclosure.f3d

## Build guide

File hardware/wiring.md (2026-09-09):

# Wiring — ST7789 ↔ ESP32-C3 SuperMini

Nets match [`schematics/tty-buddy/`](schematics/tty-buddy/) and firmware [`include/User_Setup.h`](../firmware/include/User_Setup.h) /
[`src/osd.cpp`](../firmware/src/osd.cpp).

PDF: [`schematics/tty-buddy/export/tty-buddy-schematic.pdf`](schematics/tty-buddy/export/tty-buddy-schematic.pdf).

| ST7789 | ESP32-C3 SuperMini | Role |
|---|---|---|
| GND | GND | Ground |
| VCC | 3V3 | Power |
| SCL (SCK) | GPIO4 | SPI clock |
| SDA (MOSI) | GPIO6 | SPI data |
| SDA-O (MISO) | — | Not connected |
| RST | GPIO2 | Reset |
| DC | GPIO3 | Data / command |
| CS | GPIO7 | Chip select |
| BL | GPIO5 | Backlight PWM |

| Control | ESP32-C3 SuperMini | Notes |
|---|---|---|
| SW1 | GPIO10 → GND | Firmware uses internal pull-up |

Power: USB on the SuperMini.

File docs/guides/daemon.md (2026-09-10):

# Daemon package lifecycle

Covers what the packages install, how install/upgrade behave, and how to
remove them.

## What gets installed

| Path | Purpose |
|---|---|
| `/usr/bin/tty-buddy` | Daemon binary |
| `/usr/lib/systemd/system/tty-buddy@.service` | Default unit; instance = Linux username |
| `/usr/lib/systemd/system/tty-buddy-board@.service` | Opt-in multi-board unit; instance = board id |
| `/etc/udev/rules.d/99-tty-buddy.rules` | `303a:1001` → `/dev/tty-buddy` and `/dev/tty-buddy-<serial>` |
| `/etc/tty-buddy/daemon.toml` | Host settings (created if missing) |
| `/etc/tty-buddy/buddy.config` | Panel config (created if missing) |
| `/etc/tty-buddy/instances/<id>/` | Per-board configs (created by `add-board`) |
| `/usr/lib/tty-buddy/configure-instance.sh` | Shared post-install helper |
| `/usr/lib/tty-buddy/uninstall.sh` | Tarball uninstall only |

`tty-buddy@.service` runs as `User=%i` / `Group=%i` with supplementary
`dialout` and `input`, working directory `/etc/tty-buddy`, and:

```text
ExecStart=/usr/bin/tty-buddy run --config /etc/tty-buddy/daemon.toml
```

`tty-buddy-board@.service` uses `/etc/tty-buddy/instances/%i/` for config and
working directory; `User=` / `Group=` come from a drop-in written by
`configure-instance.sh add-board` (see [Several boards](#several-boards-on-one-host)).

`Restart=always` with a short delay — the process reconnects when the USB
device disappears.

## Instance user

Install must bind to a **non-root** account. That account is:

- the systemd instance (`tty-buddy@alice`)
- `shell_user` in `daemon.toml` (login shell identity inside the PTY)
- owner of `buddy.config` (so the user can edit it without root)
- added to `dialout` and `input`

Detection:

- **`.deb` postinst:** `TTY_BUDDY_USER`, else `SUDO_USER`
- **tarball `install.sh`:** same; refuses root-only sudo with no user

Override example:

```bash
sudo TTY_BUDDY_USER=alice ./install.sh
```

`configure-instance.sh` also:

- migrates legacy `status.config` → `buddy.config` when needed
- prepends a default `[behavior]` block if missing
- sets `shell_user` when it is missing or still `REPLACE_ME`
- disables a leftover non-template `tty-buddy.service` if present
- `enable --now tty-buddy@<user>`

New `dialout`/`input` membership often requires a new login session before
the daemon can open the keyboard or serial node without permission errors.

`shell_user` is not a separate login or PAM handoff. The daemon runs as the
systemd instance user and spawns that same user’s login shell inside the PTY.
A mismatched `shell_user` now aborts startup instead of pretending to switch
users.

## Keyboard on the host

USB keyboards are opened by the daemon from an **allowlist** in
`buddy.config` (`keyboard_devices`). Prefer `/dev/input/by-id/…-event-kbd`
(not mouse, hidraw, or joystick nodes):

```bash
ls /dev/input/by-id/
```

```ini
[behavior]
keyboard_opens_terminal = false
keyboard_layout = us
keyboard_devices = /dev/input/by-id/usb-…-event-kbd
# or: keyboard_devices = NuPhy, Logitech
```

- **Empty `keyboard_devices`** — no keyboards are opened (watch or grab). The
  daemon logs a warning. Terminal mode still works from the device button /
  host stdin when interactive, but USB keys do nothing until allowlisted.
- Entries are comma-separated **absolute paths** and/or **case-insensitive
  name substrings** (sysfs device name). Paths are canonicalized when
  opened.
- `keyboard_layout` (`us` / `pl` / `de`) maps raw Linux keycodes to PTY
  bytes (not desktop XKB). Modifiers (Shift/Ctrl/Caps/AltGr) are tracked per
  device. `pl` AltGr types Polish diacritics; `de` AltGr types common third-level
  symbols. Also maps F1–F12 and Delete/Home/End/PgUp/PgDn.

Default shipped `[behavior]` sets `keyboard_opens_terminal = false`. For a
**kiosk** / dedicated console (status typing opens terminal), set it to `true`.

- In **status mode**, allowlisted keyboards are watched without grab when
  auto-open is enabled. Key activity can switch the panel into terminal mode.
- In **terminal mode**, the daemon always **EVIOCGRAB**s allowlisted
  keyboards (even if `keyboard_opens_terminal = false`), which can steal the
  desktop keyboard while the session is active.

Allowlist only the keyboard you intend for the panel. Full key table:
[configuration reference](../reference/configuration.md#behavior).

## Install / upgrade — `.deb`

Artifacts: `tty-buddy_<version>_amd64.deb` or `_arm64.deb`.

```bash
sudo apt-get install -y ./tty-buddy_<version>_amd64.deb
```

Same command upgrades. dpkg conffiles are `/etc/tty-buddy/daemon.toml` and
`buddy.config`. On upgrade, apt may prompt (or keep old files with
`--force-confold`). Binary, unit, udev, and helper scripts always refresh.

If postinst could not infer a user, it prints how to run
`configure-instance.sh` manually.

## Install / upgrade — tarball

Artifacts: `tty-buddy-<version>-x86_64-linux.tar.gz` or
`tty-buddy-<version>-aarch64-linux.tar.gz`.

```bash
tar xzf tty-buddy-<version>-x86_64-linux.tar.gz
cd tty-buddy-<version>-x86_64-linux
sudo ./install.sh
```

`install.sh` always replaces the binary, unit, udev rule, and helpers. It
**does not** overwrite existing `/etc/tty-buddy/daemon.toml` or
`buddy.config`. First install copies defaults from the tarball’s `etc/`.

Upgrade = unpack the new tarball and run `install.sh` again, then restart if
the unit was already running:

```bash
sudo systemctl restart tty-buddy@$USER
```

## After install checks

```bash
systemctl status tty-buddy@$USER
ls -l /dev/tty-buddy
journalctl -u tty-buddy@$USER -n 50 --no-pager
```

Missing symlink: replug USB, `udevadm trigger`, confirm the rule is
installed. Permission denied on `/dev/input` or serial: ensure the user is in
`dialout` and `input` (install adds both), then log out/in. The daemon logs
EACCES with an `input` group hint. Set `keyboard_devices` (see
[Keyboard on the host](#keyboard-on-the-host)) or USB keys stay idle.

## Several boards on one host

udev always creates `/dev/tty-buddy`. When the USB device has a serial, it
also creates `/dev/tty-buddy-<serial>` (stable multi-board pin). With more
than one board plugged in, bare `/dev/tty-buddy` is ambiguous — pin each
board explicitly.

**Default single-board path** (no extra setup): `tty-buddy@$USER` +
`/etc/tty-buddy/daemon.toml` + `/dev/tty-buddy`.

**Extra boards** — one systemd unit and config dir per board:

```bash
tty-buddy devices
sudo /usr/lib/tty-buddy/configure-instance.sh add-board "$USER" '<serial>'
systemctl status "tty-buddy-board@$(echo '<serial>' | tr ':/' '-')"
```

`add-board` creates `/etc/tty-buddy/instances/<id>/` (`daemon.toml` +
`buddy.config`), writes a `User=` drop-in for `tty-buddy-board@<id>`, and
enables the unit. Instance id defaults to the serial with `:`/`/` replaced
by `-`. Pass a fourth argument to override the id.

Alternatively pin the default unit only:

```bash
tty-buddy setup --config /etc/tty-buddy/daemon.toml
sudo systemctl restart tty-buddy@$USER
```

`setup` writes `device_path`, `vid`, `pid`, `serial`, and `shell_user`. If
`serial` is set and no board matches, discovery **fails closed** (does not
pick another device).

## Uninstall

Pick **one** path per packaging style.

### `.deb`

Keep `/etc/tty-buddy`:

```bash
sudo apt-get remove tty-buddy
```

Remove package and its conffiles:

```bash
sudo apt-get purge tty-buddy
```

`prerm` disables `tty-buddy.service`, all `tty-buddy@*`, and all
`tty-buddy-board@*` instances.

### Tarball

Keep configs:

```bash
sudo /usr/lib/tty-buddy/uninstall.sh
```

Also delete `/etc/tty-buddy`:

```bash
sudo /usr/lib/tty-buddy/uninstall.sh --purge
```

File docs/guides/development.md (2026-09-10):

# Development

How to build, test, package, and release from a checkout. Day-to-day install
and flash steps live in [daemon](daemon.md) and [flashing](flashing.md).
Runtime split: [architecture](../architecture/overview.md).

## Prerequisites

| Piece | Needs |
|---|---|
| Firmware | PlatformIO Core (`pio`) |
| Daemon compile / test | Rust stable ([`daemon/rust-toolchain.toml`](../../daemon/rust-toolchain.toml): `rustfmt`, `clippy`), `pkg-config`, `libudev-dev` |
| Packages on this Linux host | `dpkg-deb` / `dpkg-dev` for `.deb` |
| Packages from macOS or foreign arch | Docker (`rust:1-bookworm`, `--platform linux/amd64` or `linux/arm64`) |

The daemon targets **Linux** (udev serial discovery, `/dev/input`, systemd
packaging). You can edit and run unit tests on other hosts where crates
compile; runtime and packages assume Linux amd64/arm64.

**Single version string:** [`daemon/Cargo.toml`](../../daemon/Cargo.toml) `version`. [`Makefile`](../../Makefile),
firmware inject/merge scripts, and CI all read that field. Firmware UI label
is `version/DD.MM.YY` (local build date) via [`inject_version.py`](../../firmware/scripts/inject_version.py).

## Layout

| Path | Role |
|---|---|
| [`firmware/`](../../firmware/) | PlatformIO device + native protocol tests |
| [`daemon/`](../../daemon/) | Rust crate (`tty_buddy` lib + `tty-buddy` bin) |
| [`daemon/packaging/`](../../daemon/packaging/) | `.deb` / tarball builders, unit, install helpers |
| [`daemon/udev/`](../../daemon/udev/) | `99-tty-buddy.rules` |
| [`scripts/`](../../scripts/) | [`write-checksums.sh`](../../scripts/write-checksums.sh), [`changelog-section.sh`](../../scripts/changelog-section.sh) |
| [`dist/`](../../dist/) | Root artifact folder (`make` / release CI) |

Library modules under [`daemon/src/lib.rs`](../../daemon/src/lib.rs): `bridge`, `discover`, `keyboard`,
`metrics`, `protocol`, `serial_io`, `settings`, `status_config`, `terminal`.
Wire format: [protocol](../reference/protocol.md).

## Make targets

From the repository root ([`Makefile`](../../Makefile)). `VERSION` defaults to the Cargo
version; override with `make VERSION=…` only if you know why.

| Target | Result |
|---|---|
| `make help` / `make version` | Print targets / version |
| `make firmware` | `pio run` → copy factory bin to `dist/tty-buddy-firmware-<ver>.bin` |
| `make daemon` | Host-arch `.deb` + tarball into `dist/` |
| `make daemon-all` | amd64 **and** arm64 packages (uses Docker when arch ≠ host) |
| `make checksums` | `dist/checksums.txt` for whatever is already in `dist/` |
| `make release` | `firmware` + `daemon` + `checksums` |
| `make release-all` | `firmware` + `daemon-all` + `checksums` |
| `make clean` | Remove `dist/`, `firmware/dist`, `daemon/dist`, PIO/cargo clean |

Packaging scripts also write under `daemon/dist/` and honour `DEST` (Make
sets `DEST=dist`). Artifact names:

```text
tty-buddy-firmware-<ver>.bin
tty-buddy_<ver>_amd64.deb | tty-buddy_<ver>_arm64.deb
tty-buddy-<ver>-x86_64-linux.tar.gz | tty-buddy-<ver>-aarch64-linux.tar.gz
checksums.txt
```

## Firmware pipeline

Env [`esp32-c3-supermini`](../../firmware/platformio.ini) (default): Arduino + TFT_eSPI, USB CDC on boot
(`ARDUINO_USB_MODE` / `ARDUINO_USB_CDC_ON_BOOT`), pins from [`User_Setup.h`](../../firmware/include/User_Setup.h)
and [`osd.cpp`](../../firmware/src/osd.cpp) (`GPIO5` BL, `GPIO10` button). Wiring: [`hardware/wiring.md`](../../hardware/wiring.md).

`extra_scripts` on that env:

1. **pre** [`inject_version.py`](../../firmware/scripts/inject_version.py) — `TTY_BUDDY_VERSION` from Cargo + date.
2. **pre** [`fix_tft_espi_c3.py`](../../firmware/scripts/fix_tft_espi_c3.py) — patches TFT_eSPI’s ESP32-C3 `SPI_PORT`
   (`SPI2_HOST` vs `REG_SPI_BASE` expecting `2`) under `.pio/libdeps/…`.
   Idempotent; skips if the header is not downloaded yet (first resolve may
   need a second build).
3. **post** [`merge_factory.py`](../../firmware/scripts/merge_factory.py) — `esptool merge_bin` of bootloader `@0x0`,
   partitions `@0x8000`, `boot_app0` `@0xe000`, app `@0x10000` →
   `firmware/dist/tty-buddy-firmware-<ver>.bin` (flash at **0x0**). Skipped
   for the `native` env.

`make firmware` fails if that merged file is missing after `pio run`.

Env **`native`**: Unity tests with `test_build_src` filtered to
[`protocol.cpp`](../../firmware/src/protocol.cpp) and
[`glyph_font.cpp`](../../firmware/src/glyph_font.cpp)
([`firmware/test/test_protocol/`](../../firmware/test/test_protocol/),
[`firmware/test/test_glyphs/`](../../firmware/test/test_glyphs/)). Do
**not** run `pio run -e native` — there is no `main()` outside the test
harness.

Unicode cell bitmaps for **Polish and German** diacritics live in
[`glyph_unicode_data.h`](../../firmware/src/glyph_unicode_data.h), generated
via [`scripts/gen_unicode_glyphs.py`](../../firmware/scripts/gen_unicode_glyphs.py)
(font8x8 Public Domain + Unifont SIL OFL 1.1). Other non-ASCII still shows
`?` aside from procedural box/block/Braille.

### Local firmware loop

```bash
cd firmware
pio test -e native
pio run -e esp32-c3-supermini
./scripts/flash.sh          # PIO upload (bootloader + app offsets)
# or flash the merged factory image:
./scripts/flash.sh ../dist/tty-buddy-firmware-$(make -C .. -s version).bin
```

[`flash.sh`](../../firmware/scripts/flash.sh) stops running `tty-buddy@*` and
`tty-buddy-board@*` when systemd is present. Details: [flashing](flashing.md).

Serial monitor (CDC, 115200):

```bash
cd firmware
pio device monitor -e esp32-c3-supermini
```

## Daemon pipeline

Release profile uses LTO + `codegen-units = 1` ([`Cargo.toml`](../../daemon/Cargo.toml)).

### Checks (same as CI)

[`.github/workflows/ci.yml`](../../.github/workflows/ci.yml) on `main` / PRs:

```bash
cd daemon
cargo fmt --all -- --check
cargo clippy --all-targets -- -D warnings
cargo test
cargo build --release   # CI also does this
```

```bash
cd firmware
pio test -e native
pio run -e esp32-c3-supermini
# CI asserts firmware/dist/tty-buddy-firmware-<ver>.bin exists
```

Unit coverage is concentrated in `protocol`, `status_config`, `metrics`,
`settings`, `discover`, `keyboard`, `terminal` (`#[cfg(test)]` in those
files). There is no hardware-in-the-loop job in CI.

### Run without packaging

```bash
cd daemon
cargo run --release --bin tty-buddy -- devices
cargo run --release --bin tty-buddy -- probe --buddy-config ./buddy.config
cargo run --release --bin tty-buddy -- run --config /path/to/daemon.toml
```

`--port`, `--buddy-config`, `--fps`, `--status` / `--terminal` override
config for that process only ([configuration](../reference/configuration.md)). Prefer `tty-buddy@$USER` on a
real host so udev groups and restart policy match production ([daemon](daemon.md)).

## Packaging internals

Entry points:

- [`build-deb.sh`](../../daemon/packaging/build-deb.sh)
- [`build-linux-release.sh`](../../daemon/packaging/build-linux-release.sh)
- shared arch resolution: [`arch.sh`](../../daemon/packaging/arch.sh)
- binary: [`build-binary.sh`](../../daemon/packaging/build-binary.sh)

[`build-binary.sh`](../../daemon/packaging/build-binary.sh) runs `cargo build --release` **natively** only when the
host is Linux **and** matches the requested deb arch. Otherwise it builds
inside Docker (`--platform linux/amd64` or `linux/arm64`, `rust:1-bookworm`
+ `libudev-dev`). So:

- Linux amd64 → native amd64 packages; arm64 packages need Docker (or an ARM
  runner).
- macOS → always Docker for both arches (and for `dpkg-deb` if missing —
  `build-deb.sh` re-enters itself in the container).

`.deb` ships binary, `tty-buddy@` / `tty-buddy-board@` units, udev,
`configure-instance.sh`, and default `daemon.toml` / `buddy.config`. Tarball
adds `install.sh` / `uninstall.sh`. Behaviour after install: [daemon](daemon.md).

## Release workflow

[`.github/workflows/release.yml`](../../.github/workflows/release.yml):

| Trigger | Behaviour |
|---|---|
| Push tag `v*` | Build all artifacts; tag must equal Cargo version (`v1.0.0` ↔ `1.0.0`); **draft** GitHub Release |
| `workflow_dispatch` | Always builds artifacts; creates/updates a draft release only if `tag` input is set |

Jobs: firmware (`make firmware`), daemon matrix (amd64 on `ubuntu-latest`,
arm64 on `ubuntu-24.04-arm`), then aggregate + [`write-checksums.sh`](../../scripts/write-checksums.sh). Release
notes body = [`changelog-section.sh`](../../scripts/changelog-section.sh) for that version from [`CHANGELOG.md`](../../CHANGELOG.md)
(Keep a Changelog section must be non-empty).

### Checklist before tagging

1. Bump `version` in [`daemon/Cargo.toml`](../../daemon/Cargo.toml).
2. Add `## [<ver>] - YYYY-MM-DD` under Keep a Changelog in [`CHANGELOG.md`](../../CHANGELOG.md)
   (not only `[Unreleased]`).
3. Align root README version line if you treat it as released (owned by
   `/readme`).
4. Local smoke (optional): `make release` or `make release-all`, flash
   factory bin, install package on a Linux host.
5. `git tag v<ver> && git push origin v<ver>`.
6. Publish the draft release on GitHub after checking assets and notes.

Local preview of notes:

```bash
./scripts/changelog-section.sh 1.0.0 CHANGELOG.md
```

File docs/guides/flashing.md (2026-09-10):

# Flashing firmware

## Which file to flash

Releases and `make firmware` produce a **merged factory** image:

`tty-buddy-firmware-<version>.bin`

That blob is bootloader + partition table + `boot_app0` + application, laid
out for a write starting at **flash offset 0x0**. Size is on the order of
hundreds of KB (far larger than an app-only binary).

The PlatformIO build also emits
`firmware/.pio/build/esp32-c3-supermini/firmware.bin`. That file is
**application only** and belongs at **0x10000** together with separate
bootloader/partition images. Flashing it alone at `0x0` bricks the layout.
The repo `flash.sh` refuses merged-at-0x0 flashes for images that look too
small.

Version string inside the image comes from `daemon/Cargo.toml` via
`firmware/scripts/inject_version.py` (label also includes a build date).

## Serial port ownership

The host daemon opens the CDC port exclusively. Web flashers and esptool
need it free:

```bash
sudo systemctl stop 'tty-buddy@*' 'tty-buddy-board@*'
```

`firmware/scripts/flash.sh` stops running `tty-buddy.service`,
`tty-buddy@*`, and `tty-buddy-board@*` units when systemd is present, then
restarts the ones it stopped after a successful flash.

Port discovery in `flash.sh`:

1. `/dev/tty-buddy` (udev symlink for `303a:1001`)
2. Otherwise first `/dev/ttyACM*` / `/dev/ttyUSB*` with vendor `303a` and
   product `1001`

Override with `--port`.

## Browser (Web Serial)

Requires the **Web Serial** API: **Chrome** or **Edge 89+**. Not Firefox or
Safari. Origin must be secure (HTTPS); the public tools already are.

| Tool | URL |
|---|-----|
| Espressif esptool-js | https://espressif.github.io/esptool-js/ |
| Adafruit WebSerial ESPTool | https://adafruit.github.io/Adafruit_WebSerial_ESPTool/ |

Procedure:

1. Stop the daemon (above).
2. Plug the board in over USB.
3. In the tool, connect the Espressif USB Serial/JTAG interface.
4. Select `tty-buddy-firmware-<version>.bin`.
5. Program at address **0x0** (full chip image — not an app offset like
   `0x10000`).
6. Wait for verify / reset. If the panel stays black, unplug/replug once.

Failures are usually another process holding the port, a bad cable/hub, or a
Chrome Web Serial regression (update the browser). Android Chrome may work
via WebUSB polyfills in some tools; desktop Chrome/Edge is the supported
path.

## Command line on a machine with the board attached

### Factory image (release / `make firmware`)

```bash
cd firmware
./scripts/flash.sh /path/to/tty-buddy-firmware-<version>.bin
```

```bash
./scripts/flash.sh --port /dev/ttyACM0 /path/to/tty-buddy-firmware-<version>.bin
```

Uses esptool (`esptool.py`, `esptool`, or PlatformIO’s bundled copy) roughly
as:

```bash
esptool.py --chip esp32c3 --port <PORT> --baud 921600 \
  --before default_reset --after hard_reset \
  write_flash -z 0x0 tty-buddy-firmware-<version>.bin
```

### PlatformIO incremental upload (dev)

No path argument uploads bootloader, partitions, `boot_app0`, and app at the
offsets PlatformIO expects (not a single `0x0` merge):

```bash
cd firmware
./scripts/flash.sh
# equivalent: pio run -e esp32-c3-supermini -t upload --upload-port <PORT>
```

Prefer the factory `.bin` when installing from a release so the on-device
partition set matches what CI built.

## After flashing

- USB may renumerate; wait for `/dev/tty-buddy` or the ACM node to reappear.
- Start the daemon again if `flash.sh` did not (or if you stopped it by
  hand):

```bash
sudo systemctl start tty-buddy@$USER
# if you use board instances:
# sudo systemctl start 'tty-buddy-board@*'
```

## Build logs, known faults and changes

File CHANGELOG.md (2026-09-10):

# Changelog

All notable changes to this project are documented in this file.

The format is based on [Keep a Changelog](https://keepachangelog.com/en/1.1.0/),
and this project adheres to [Semantic Versioning](https://semver.org/spec/v2.0.0.html).

## [Unreleased]

## [1.1.0] — 2026-09-10

### Added

- `[behavior] keyboard_devices` allowlist: comma-separated `/dev/input/by-id/…`
  paths and/or case-insensitive name substrings; empty list opens **no**
  keyboards (watch or grab) and logs a warning
- `[behavior] keyboard_layout` (`us` / `pl` / `de`) for daemon evdev→PTY mapping
  (not XKB). `pl` is QWERTZ Y/Z with a US digit row; `de` emits German letters
  from the key map
- CapsLock, AltGr (PL diacritics / DE third level), F1–F12, and
  Delete/Home/End/PgUp/PgDn; Shift/Ctrl/Caps/AltGr tracked **per keyboard
  device**
- Firmware terminal glyphs for curated Polish and German diacritics (6×8), with
  a generator script and native unit tests
- udev serial-suffixed nodes `/dev/tty-buddy-<serial>` alongside `/dev/tty-buddy`
- Opt-in multi-board packaging: `tty-buddy-board@<id>`,
  `/etc/tty-buddy/instances/<id>/`, and
  `configure-instance.sh add-board <user> <serial> [id]`

### Changed

- Host keyboards are no longer auto-discovered by name heuristics; configure
  `keyboard_devices` after install or USB keys stay idle
- Buddy-config reload reapplies keyboard allowlist/layout in both status
  (watch/ungrab) and terminal (re-grab)
- Docs and README cover allowlist, layouts, fail-closed serial discovery, and
  PL/DE display glyphs
- Shipped default `keyboard_opens_terminal` is `false` (kiosk / dedicated
  console: set `true`); EACCES on `/dev/input` logs an `input` group hint

### Fixed

- `daemon.toml` `serial` pin is fail-closed: an unmatched serial no longer
  falls through to another board
- OSD `buddy.config` writes use temp-file + rename when the directory allows
  it; otherwise overwrite in place (root-owned `/etc/tty-buddy` + user-owned
  config)
- StatusSnap string fields truncate on UTF-8 boundaries (`pad_str`)
- Filtered `[services]` queries use one batched `systemctl is-active` instead of
  per-unit `show` / `is-active` forks

### Removed

- Fail-open `DaemonSettings::load_or_default` (unused). Callers use `load`,
  which still defaults on a missing file and errors on invalid/unreadable TOML.

## [1.0.1] — 2026-09-09

### Changed

- Status metrics still refresh about once per second from `/proc`, but `ip` and
  `systemctl` results are cached for a few seconds to cut host CPU use
- Shipped `buddy.config` leaves `[interfaces]` empty (add only the ifaces you
  want shown); packaging only rewrites `shell_user = "REPLACE_ME"`
- Docs and README spell out keyboard watch/grab behaviour and the
  `wake_on_alert` sleep policy (alert holds sleep off until it clears; OSD
  idle-close still runs)

### Fixed

- Invalid or unreadable `daemon.toml` aborts `run` / `setup` instead of
  silently falling back to defaults
- `shell_user` must match the `tty-buddy@<user>` runtime user; a mismatch
  fails startup (the daemon never switches uid — it runs `$SHELL -l` as that
  user)
- Device presence checks the configured path (and that discovery still
  resolves to it), not “any Espressif CDC still exists”
- Reversed `[hero]` `warn_at` / `crit_at` values are swapped after parse
- Serial inbox drops non-opcode noise and caps growth; three consecutive
  framed-send failures drop the session again (idle ticks no longer reset
  the fail counter)
- `FLAG_STYLE` updates refresh status chrome while already in status mode

### Removed

- Packaging special-case for author `shell_user = "dih"`

## [1.0.0] — 2026-09-09

First public release: ESP32-C3 + ST7789 status/console buddy with a Linux
host daemon over USB-Serial/JTAG.

### Added

- **Status mode** on a 320×240 panel: hostname and clock, CPU / MEM / DISK
  meters with warn/crit colours, optional secondary fields (uptime, load,
  swap), network interfaces, systemd service list, and a bottom alert strip
  (CPU/MEM/DISK/temp/service)
- **Terminal mode**: 53×30 VT mirror of a login shell in a PTY for `shell_user`, with
  box/block/Braille glyphs; USB keyboard on the host is watched in status
  (optional open-to-terminal) and grabbed into the console in terminal mode
- **On-device OSD** (one button): toggle mode, brightness steps or auto
  day/night, sleep timeout, dismiss alert on tap, wake-on-alert; brightness
  and sleep sync to the host and persist in NVS when the daemon is offline
- **`buddy.config`** panel INI: `[behavior]` (`startup_mode`,
  `keyboard_opens_terminal`, `fps`), layout/colours, interfaces, services
  filter, alerts, and `[display]` (legacy `status.config` / `[osd]` still
  accepted; install can migrate the filename)
- **`daemon.toml`** host settings: device path / USB id / serial,
  `buddy_config` path, and `shell_user` for the daemon runtime user
- **Linux packaging** for amd64 and arm64: `.deb` and portable tarballs,
  `tty-buddy@<user>` systemd unit, udev rule for `/dev/tty-buddy`,
  `install.sh` / `uninstall.sh` (`--purge`); install binds groups and
  `buddy.config` ownership to the installing user
- **Factory firmware** image (`tty-buddy-firmware-<ver>.bin`) for a full
  flash at offset `0x0`, plus Web Serial and `flash.sh` workflows

### Fixed

- OSD idle auto-close no longer stalls while `wake_on_alert` holds the panel
  awake for a status alert (sleep still waits until the alert clears)

[Unreleased]: https://github.com/imflawlezz/tty-buddy/compare/v1.1.0...HEAD
[1.1.0]: https://github.com/imflawlezz/tty-buddy/releases/tag/v1.1.0
[1.0.1]: https://github.com/imflawlezz/tty-buddy/releases/tag/v1.0.1
[1.0.0]: https://github.com/imflawlezz/tty-buddy/releases/tag/v1.0.0

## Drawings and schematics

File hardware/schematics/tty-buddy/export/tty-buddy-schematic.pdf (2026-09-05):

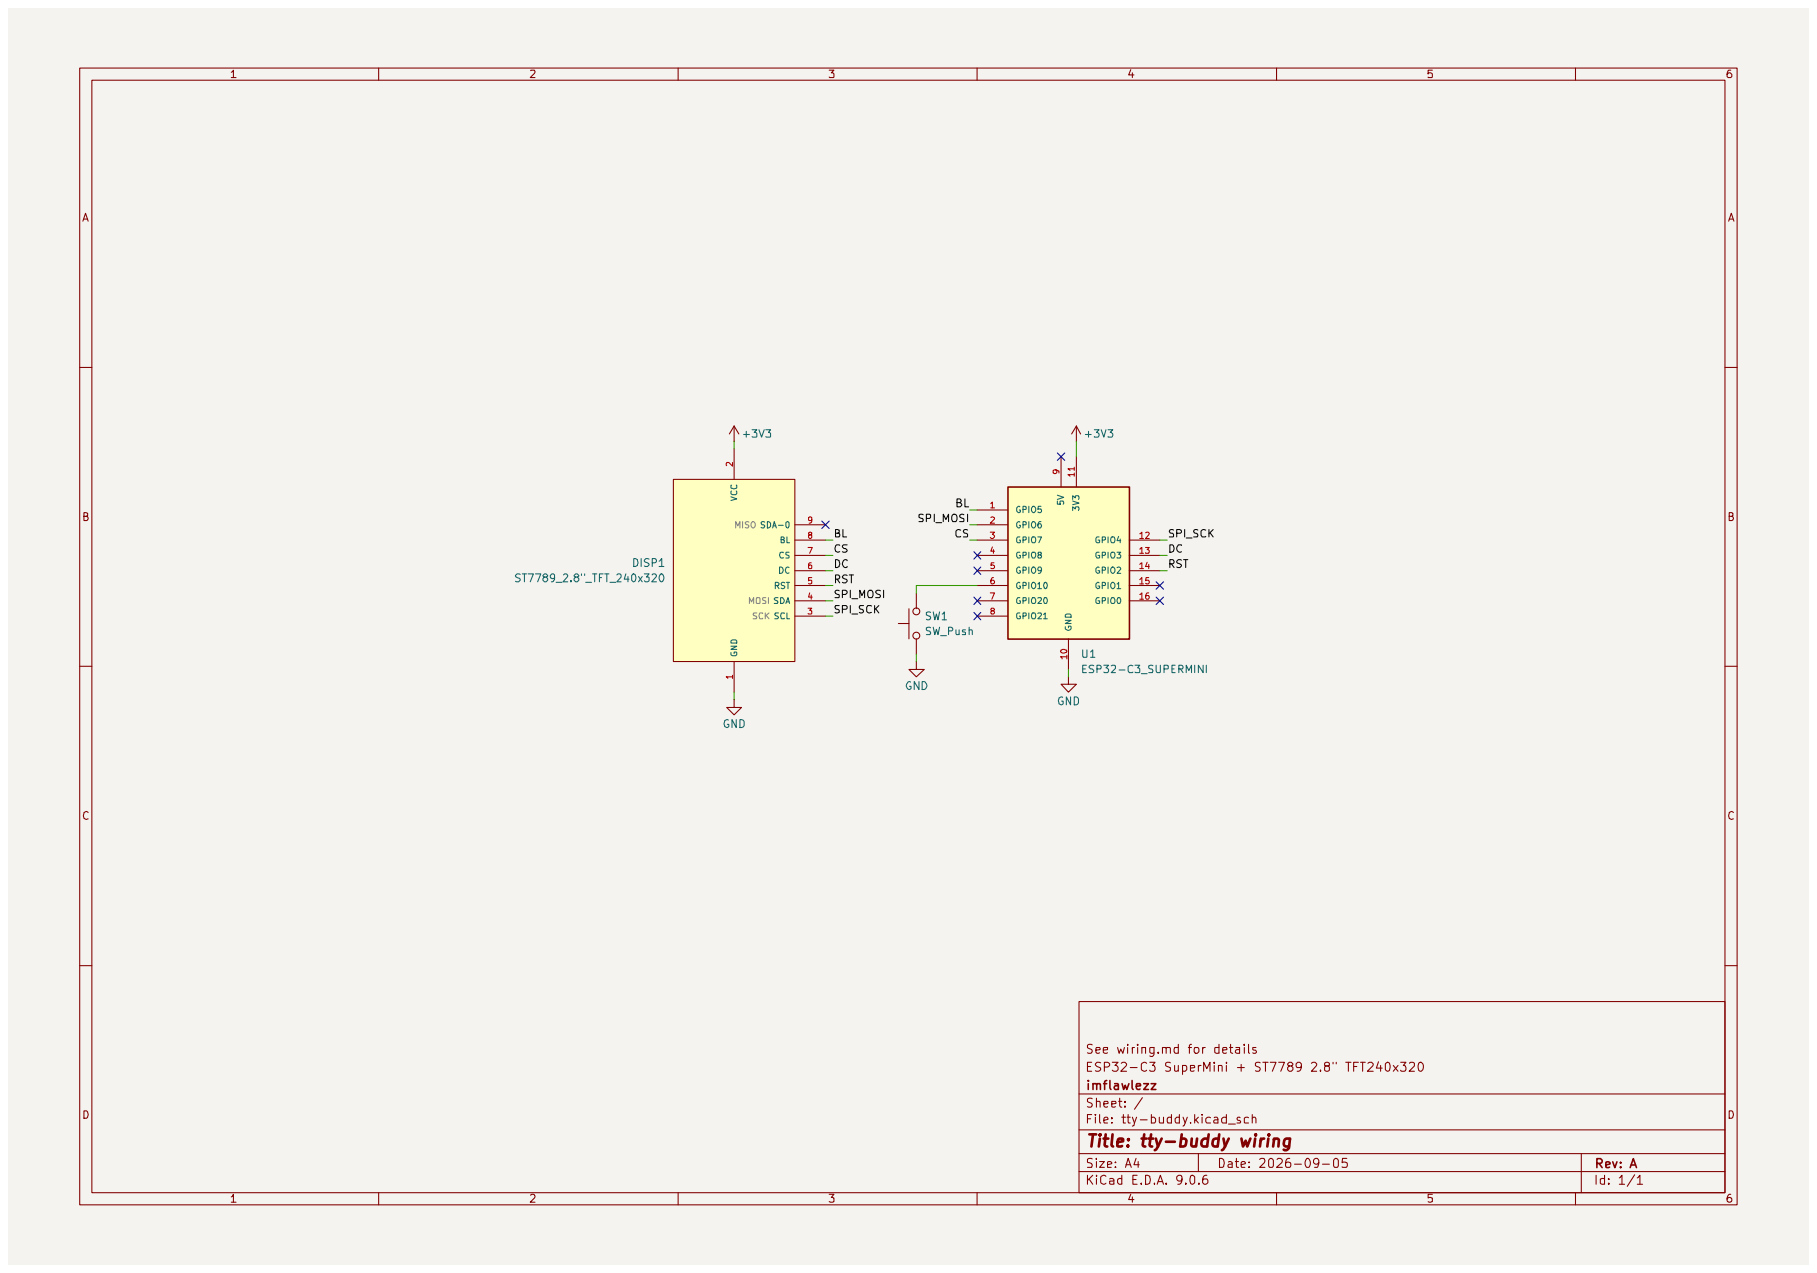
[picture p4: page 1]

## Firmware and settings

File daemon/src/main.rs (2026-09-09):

//! Host daemon for the ESP32 status display and console PTY.

use std::path::PathBuf;

use anyhow::{Context, Result};
use clap::{Parser, Subcommand};

use tty_buddy::bridge;
use tty_buddy::discover::{list_serial_devices, resolve_device};
use tty_buddy::metrics::MetricsCollector;
use tty_buddy::protocol::STATUS_SNAP_LEN;
use tty_buddy::settings::{resolve_buddy_config_path, settings_path, DaemonSettings};
use tty_buddy::status_config::load_status_config;

#[derive(Parser, Debug)]
#[command(name = "tty-buddy", about = "ESP32 tty-buddy host daemon")]
struct Cli {
    #[command(subcommand)]
    cmd: Commands,
}

#[derive(Subcommand, Debug)]
enum Commands {
    /// Interactive device picker; writes daemon.toml
    Setup {
        #[arg(long)]
        config: Option<PathBuf>,
    },
    /// Run as daemon (reconnect forever). Used by systemd.
    Run {
        #[arg(long)]
        config: Option<PathBuf>,
        #[arg(short, long)]
        port: Option<String>,
        #[arg(long, visible_alias = "status-config")]
        buddy_config: Option<PathBuf>,
        #[arg(long)]
        fps: Option<f32>,
        /// Force start in status mode
        #[arg(long)]
        status: bool,
        /// Force start in terminal/console mode
        #[arg(long)]
        terminal: bool,
    },
    /// List USB serial devices
    Devices,
    /// Sample live host metrics (no serial)
    Probe {
        #[arg(long, visible_alias = "status-config")]
        buddy_config: Option<PathBuf>,
    },
}

fn main() -> Result<()> {
    let cli = Cli::parse();
    match cli.cmd {
        Commands::Devices => {
            for d in list_serial_devices()? {
                println!("{d}");
            }
            Ok(())
        }
        Commands::Probe { buddy_config } => cmd_probe(buddy_config),
        Commands::Setup { config } => cmd_setup(config),
        Commands::Run {
            config,
            port,
            buddy_config,
            fps,
            status,
            terminal,
        } => cmd_run(config, port, buddy_config, fps, status, terminal),
    }
}

fn runtime_user() -> String {
    std::env::var("USER")
        .or_else(|_| std::env::var("LOGNAME"))
        .unwrap_or_else(|_| "root".into())
}

fn validate_shell_user(settings: &DaemonSettings) -> Result<()> {
    let Some(shell_user) = settings.shell_user.as_deref() else {
        return Ok(());
    };
    let current = runtime_user();
    if shell_user != current {
        anyhow::bail!(
            "shell_user={} does not match the daemon runtime user={current}; run tty-buddy@{shell_user} or set shell_user to {current}",
            shell_user
        );
    }
    Ok(())
}

fn cmd_setup(config: Option<PathBuf>) -> Result<()> {
    use std::io::{stdin, stdout, Write};
    let path = config.unwrap_or_else(settings_path);
    let devices = list_serial_devices()?;
    if devices.is_empty() {
        anyhow::bail!("no serial devices found — plug in the ESP first");
    }

    println!("tty-buddy setup — pick serial device\n");
    for (i, d) in devices.iter().enumerate() {
        println!("  [{i}] {d}");
    }
    print!("\nNumber [0]: ");
    stdout().flush()?;
    let mut line = String::new();
    stdin().read_line(&mut line)?;
    let idx: usize = {
        let t = line.trim();
        if t.is_empty() {
            0
        } else {
            t.parse().context("invalid selection")?
        }
    };
    let chosen = devices.get(idx).context("selection out of range")?;

    print!("Linux login user for on-device console [{}]: ", whoami());
    stdout().flush()?;
    line.clear();
    stdin().read_line(&mut line)?;
    let user = {
        let t = line.trim();
        if t.is_empty() {
            whoami()
        } else {
            t.to_string()
        }
    };

    let mut settings = DaemonSettings::load(&path)?;
    settings.device_path = Some(chosen.path.clone());
    settings.vid = chosen.vid;
    settings.pid = chosen.pid;
    settings.serial = chosen.serial.clone();
    settings.shell_user = Some(user.clone());
    if settings.buddy_config.is_none() {
        settings.buddy_config = Some(PathBuf::from("/etc/tty-buddy/buddy.config"));
    }
    settings.save(&path)?;
    println!("\nSaved {}", path.display());
    println!("  device = {}", chosen.path);
    println!("  user   = {user}");
    println!("Enable:  sudo systemctl enable --now tty-buddy@$USER");
    Ok(())
}

fn whoami() -> String {
    std::env::var("USER").unwrap_or_else(|_| "root".into())
}

fn cmd_run(
    config: Option<PathBuf>,
    port: Option<String>,
    buddy_config: Option<PathBuf>,
    fps: Option<f32>,
    status: bool,
    terminal: bool,
) -> Result<()> {
    let path = config.unwrap_or_else(settings_path);
    let mut settings = DaemonSettings::load(&path)?;
    if let Some(p) = port {
        settings.device_path = Some(p);
    }
    if let Some(sc) = buddy_config {
        settings.buddy_config = Some(sc);
    }

    let buddy_path = resolve_buddy_config_path(settings.buddy_config.as_deref());
    validate_shell_user(&settings)?;

    let mut force_status = None;
    if status {
        force_status = Some(true);
    }
    if terminal {
        force_status = Some(false);
    }

    bridge::run_forever(&settings, &buddy_path, fps, force_status)
}

fn cmd_probe(buddy_config: Option<PathBuf>) -> Result<()> {
    let path = resolve_buddy_config_path(buddy_config.as_deref());
    let cfg = load_status_config(&path)?;
    let mut m = MetricsCollector::new();
    let _ = m.sample(&cfg)?;
    std::thread::sleep(std::time::Duration::from_millis(250));
    let snap = m.sample(&cfg)?;
    let packed = snap.pack();
    println!("hostname     {}", snap.hostname);
    println!("date/time    {} {}", snap.date, snap.time);
    println!(
        "cpu/mem/disk {}% / {}% / {}%",
        snap.cpu_pct, snap.mem_pct, snap.disk_pct
    );
    println!(
        "load         {:.2} {:.2} {:.2}",
        snap.load_x100[0] as f32 / 100.0,
        snap.load_x100[1] as f32 / 100.0,
        snap.load_x100[2] as f32 / 100.0
    );
    println!("uptime_sec   {}", snap.uptime_sec);
    println!("mem          {}/{} MB", snap.mem_used_mb, snap.mem_total_mb);
    println!(
        "disk ({})  {}/{} MB",
        cfg.disk_mount, snap.disk_used_mb, snap.disk_total_mb
    );
    if snap.cpu_temp_c10 != 0x7FFF {
        println!("cpu_temp     {:.1} C", snap.cpu_temp_c10 as f32 / 10.0);
    }
    println!("ifaces       {}", snap.ifaces.len());
    for i in &snap.ifaces {
        println!("  {}  {}  rx={} tx={}", i.name, i.ip, i.rx_bps, i.tx_bps);
    }
    println!("services     {}", snap.services.len());
    for s in snap.services.iter().take(20) {
        println!("  {} status={}", s.name, s.status);
    }
    println!("snap_bytes   {} (expect {})", packed.len(), STATUS_SNAP_LEN);
    assert_eq!(packed.len(), STATUS_SNAP_LEN);
    let _ = resolve_device;
    println!("ok");
    Ok(())
}

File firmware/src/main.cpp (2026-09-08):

#include <Arduino.h>
#include <TFT_eSPI.h>
#include <SPI.h>

#include "osd.h"
#include "terminal.h"

static constexpr uint32_t LINK_TIMEOUT_MS = 12000;

TFT_eSPI tft;
Terminal term;

enum class LinkUI : uint8_t { Waiting, Live, Lost };

static LinkUI link_ui = LinkUI::Waiting;
static uint32_t last_flush_ms = 0;

static void paintWaiting() {
  term.showBanner("Waiting for daemon", "systemctl start tty-buddy", TFT_CYAN);
}

static void paintLost() {
  term.showBanner("Lost connection to daemon", "waiting to reconnect...",
                  TFT_ORANGE);
}

void setup() {
  Serial.setRxBufferSize(8192);
  Serial.begin(115200);
  delay(200);

  tft.init();
  tft.setRotation(1);
  tft.fillScreen(TFT_BLACK);

  term.begin(&tft);
  osd::begin(&tft, &term);
  paintWaiting();
  link_ui = LinkUI::Waiting;
}

void loop() {
  uint32_t now = millis();
  osd::tick(now);

  for (;;) {
    int avail = Serial.available();
    if (avail <= 0)
      break;
    uint8_t buf[1024];
    int n = avail > (int)sizeof(buf) ? (int)sizeof(buf) : avail;
    int got = Serial.readBytes(buf, n);
    if (got > 0)
      term.ingest(buf, (size_t)got);
  }

  // lastGoodFrameMs() is stamped during ingest — must not compare against a
  // pre-ingest millis() (unsigned underflow looks like a link timeout).
  now = millis();
  const bool bye = term.takeBye();
  const bool alive =
      term.linked() && (now - term.lastGoodFrameMs() <= LINK_TIMEOUT_MS);

  if (bye || (link_ui == LinkUI::Live && !alive)) {
    paintLost();
    link_ui = LinkUI::Lost;
  } else if (alive) {
    link_ui = LinkUI::Live;
  }

  if (link_ui == LinkUI::Live && now - last_flush_ms >= 16) {
    last_flush_ms = now;
    term.flush();
  }

  // Always last so content paint cannot overwrite the OSD.
  osd::paint();
}

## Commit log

2026-09-05 feat(firmware): add ESP32-C3 ST7789 cell-grid terminal
2026-09-05 feat(hardware): add enclosure CAD exports
    [tty-buddy-assembly.step, tty-buddy-body.3mf, tty-buddy-body.step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]
2026-09-05 feat(hardware): add KiCad schematic and wiring notes
    [tty-buddy.kicad_sch]
2026-09-05 fix(hardware): update GPIO pin assignment for SW1 in wiring notes
2026-09-05 feat(firmware): add backlight PWM, brightness button, and OSD Also resample millis after ingest so a fresh frame cannot look like a link timeout (unsigned underflow).
2026-09-05 fix(daemon): keepalive frames during static scrollback
2026-09-05 chore: ignore KiCad schematic and pcb bak files
2026-09-05 feat(terminal): draw box/block/Braille on-device instead of ASCII folds
    Send u16 codepoints in the cell frame so meters and borders keep real
    shapes; Font 1 still paints ASCII. No host glyph atlas or Pillow.
2026-09-07 feat(daemon): replace Python bridge with Rust systemd host daemon
    [bridge.rs, main.rs]
2026-09-08 fix(firmware): remove brightness OSD overlay
    Short-press still cycles backlight; the OSD punched a hole in the status header.
    [main.cpp]
2026-09-08 feat: StatusSnap v11 with flicker-free status UI and config updates Longer service names, slot-cached paints, shared-offset marquee, auto iface IP, and *_color status.config keys with neutral default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
2026-09-08 feat(status): add StatusSnap v12 bottom alert strip Crit/temp/service alerts with grouped wording, hold_sec, and a length-scaled marquee; clear strip/gutter cleanly on dismiss and status→terminal.
2026-09-08 fix(daemon): surface failed and inactive units reliably Collect all units before unfiltered truncate, and query filtered services via ActiveState so stopped units still appear.
2026-09-08 feat(protocol): bump StatusSnap to v13 with OSD style fields
    Seed brightness/sleep levels, live OSD flags, and day/night auto steps on the wire so host config can drive the on-device panel.
2026-09-08 feat(firmware): add compact button OSD with sleep and alert dismiss
    Tap navigates Mode/Brightness/Sleep, long-press edits, any press wakes sleep; overlay hole keeps status/terminal from painting through the panel.
2026-09-09 ci: build deb/tarball for amd64 and arm64 and attach checksums
2026-09-09 fix(firmware): keep OSD idle-close independent of alert wake
    wake_on_alert was refreshing activity every tick, which also blocked OSD
    auto-close until the alert cleared.
    [osd.cpp]
2026-09-09 feat(daemon): move panel UX into buddy.config with [behavior]
    Rename status.config → buddy.config; put startup_mode, keyboard_opens_terminal,
    and fps in [behavior]. daemon.toml stays host-only. Status mode can watch the
    keyboard and switch to terminal on typing.
2026-09-09 docs(hardware): rewrite README and wiring for current pinout
2026-09-09 docs: cut changelog for 1.0.0
2026-09-09 fix(daemon): fail closed on bad daemon.toml and shell_user mismatch
    [main.rs]
2026-09-09 fix(daemon): require configured path for device presence
    [bridge.rs]
2026-09-09 fix(daemon): drop serial inbox garbage and add DeviceTransport
2026-09-09 fix(daemon): make session loop testable and fix serial fail counter Idle ticks no longer reset consecutive_fail, so three real send failures drop the link. SessionOpts + DeviceTransport enable full b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
    [bridge.rs]
2026-09-10 fix(daemon): fail-closed serial device pin Unmatched serial no longer falls through to another board.
2026-09-10 feat(daemon): allowlist keyboards and add us/pl/de layouts Empty keyboard_devices opens no devices; layout maps raw keycodes without following desktop XKB.
2026-09-10 feat(daemon): add CapsLock, AltGr, F-keys, and nav keys Track modifiers per device; PL/DE AltGr layers for diacritics and third-level symbols.
2026-09-10 fix(daemon): harden OSD writes, UTF-8 pad_str, and batched systemctl Atomic config write falls back in-place when /etc/tty-buddy is not writable; filtered services use one is-active call.
2026-09-10 feat: add multi-board udev symlinks and board instances Keep /dev/tty-buddy for single-board installs; add serial-suffixed nodes and opt-in tty-buddy-board@ with per-instance configs.
2026-09-10 docs: document multi-board udev nodes and add-board setup
2026-09-10 chore: release 1.1.0 Cut Unreleased into dated 1.1.0 and bump the daemon package version.
2026-09-10 docs: clarify board units and flash/service docs for 1.1.0 Document tty-buddy-board@ separately from tty-buddy@, stop/start both unit patterns when flashing, and note batched filtered systemctl.
